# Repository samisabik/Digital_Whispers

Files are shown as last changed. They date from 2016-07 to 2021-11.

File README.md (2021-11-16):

## Digital Whispers

In a world populated by an increasing abundance of Artificial Intelligences (AI), it has become more and more important for us to understand the behaviours of our smarter machines. AI promises perfect systems designed to master their functions. As humans, we have imbued these artificial creatures with senses. We have given them the ability to communicate to an ever nearer degree of naturalness; speech and hearing being the most developed. With these efforts, we expect these systems to be as perfect as we have designed them; but what about errors? Beautiful mispronunciation? Hearing loss? Faded meaning? What about the little misunderstandings that makes us human? Can a machine suffer from them and experience them also?

Digital Whispers is an installation that sets seven computers and one human in to a game of Chinese Whispers. The visitor inputs the seed sentence into the “ear” of the first computer and the dialog of ethereal whispers continues in a chain until every machine has had its say. Each computer can hear and talk. It whispers to its neighbour the sentence as it comes into its “ears”. Errors evolves involuntary (or not), creating word chimeras, often resulting in absurd sentences only a robot could have created. The final phrase spoken back to the visitor, most often with surreal overtones, leaves to question the machine as a reflection of humanity.

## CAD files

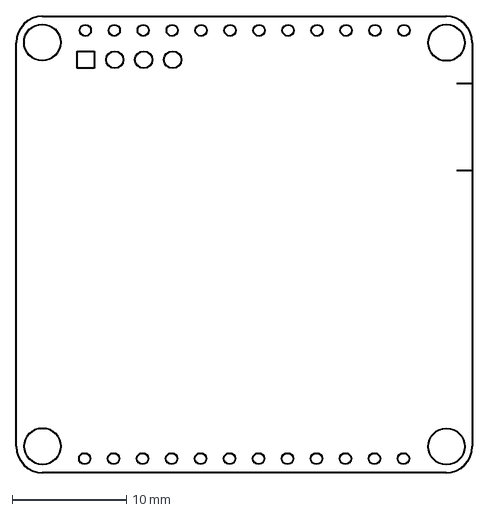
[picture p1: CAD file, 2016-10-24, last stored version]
physical/drawings/NanoPi-NEO-Air-1608.dxf
40.0 x 40.0 mm

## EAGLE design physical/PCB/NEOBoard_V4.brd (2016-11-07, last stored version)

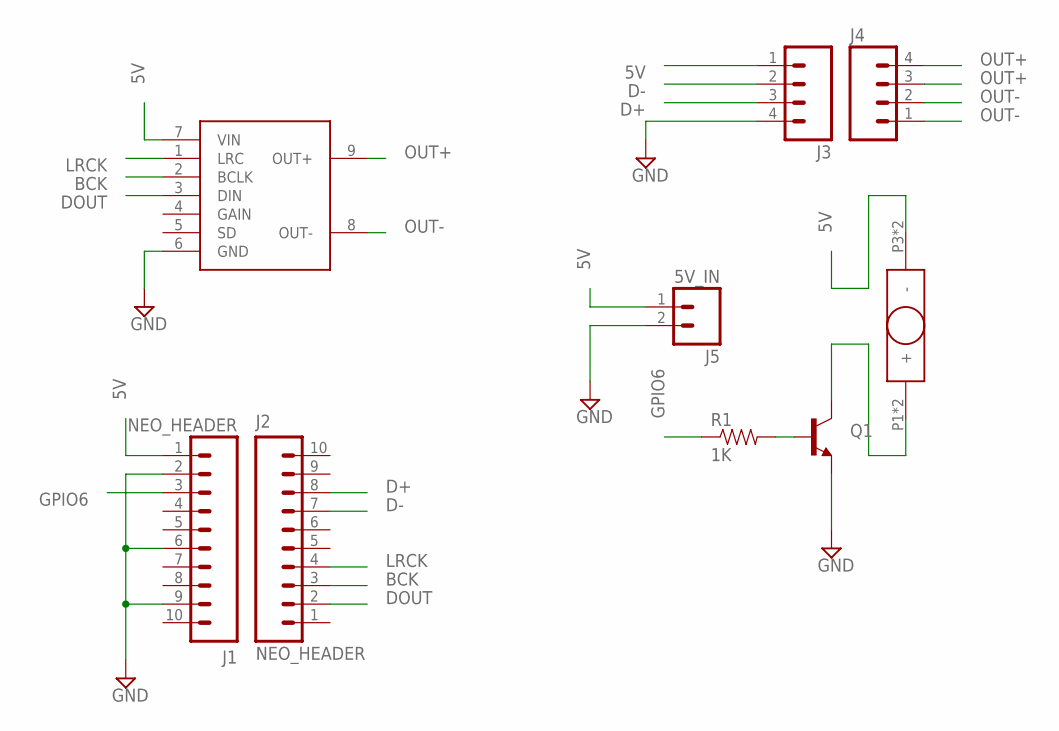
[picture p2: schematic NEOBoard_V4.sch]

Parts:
J1, J2: NEO_HEADER; 1X10_NO_SILK
J3, J4: M04NO_SILK_ALL_ROUND; 1X04_NO_SILK_ALL_ROUND
J5: 5V_IN; 1X02_NO_SILK
Q1: TRANSISTOR_NPNTO92; TO-92
R1: 1K; AXIAL-0.3
U$1: I2S_BREAKOUT
U$2: FUSER; FUSE

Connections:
5V: J1.1, J3.1, J5.1, U$1.7 (VIN), U$2.P3 (-), U$2.P4 (-)
BCK: J2.3, U$1.2 (BCLK)
D+: J2.8, J3.3
D-: J2.7, J3.2
DOUT: J2.2, U$1.3 (DIN)
GND: J1.2, J1.6, J1.9, J3.4, J5.2, Q1.1 (E), U$1.6 (GND)
GPIO6: J1.3, R1.P$1 (1)
LRCK: J2.4, U$1.1 (LRC)
unnamed: Q1.2 (B), R1.P$2 (2)
unnamed: Q1.3 (C), U$2.P1 (+), U$2.P2 (+)
OUT+: J4.3, J4.4, U$1.9 (OUT+)
OUT-: J4.1, J4.2, U$1.8 (OUT-)

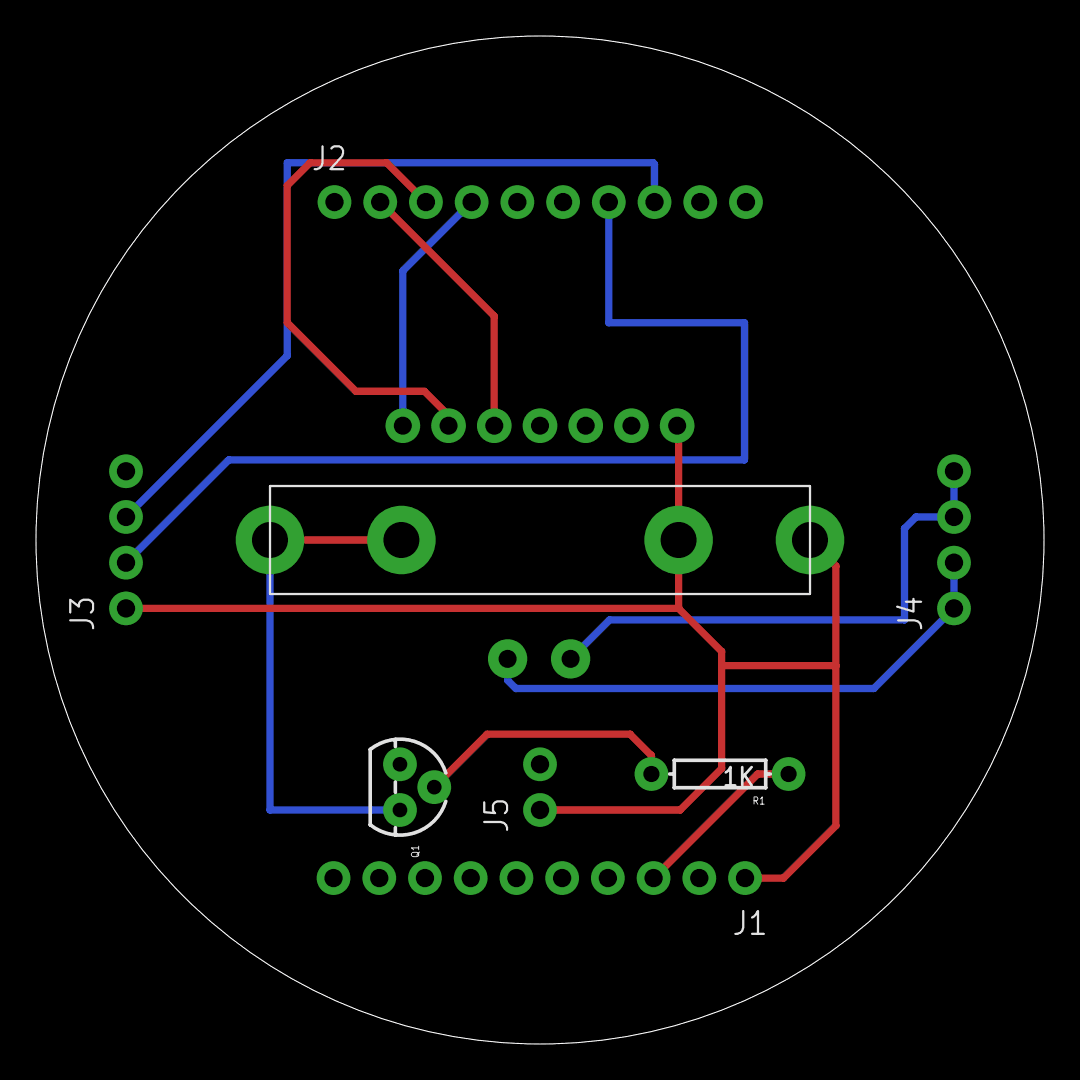
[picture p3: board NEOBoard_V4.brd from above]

Board: 2 copper layers, 56.0 x 56.0 mm, 9 parts (1 on the bottom side), 12 nets.

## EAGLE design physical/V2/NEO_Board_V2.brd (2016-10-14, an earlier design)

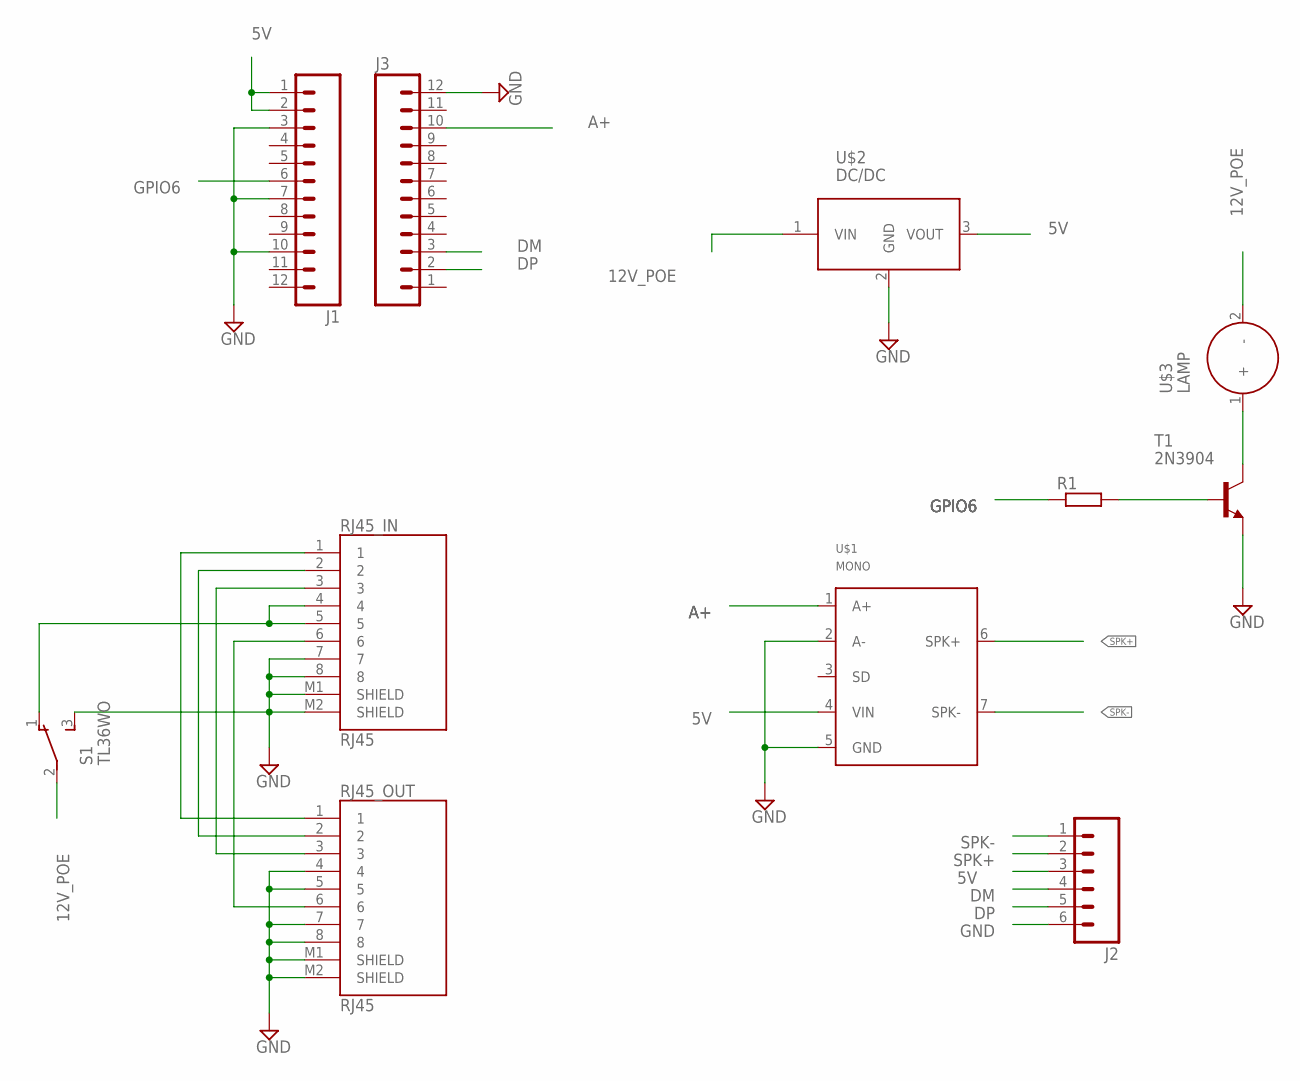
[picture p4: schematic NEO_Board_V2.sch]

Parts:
J1, J3: M12PTH; 1X12
J2: M06NO_SILK_FEMALE_PTH; 1X06_NO_SILK
R1: R-EU_0207/10; 0207/10
RJ45_IN, RJ45_OUT: RJ45
S1: TL36WO; TL3XWO
T1: 2N3904; TO92
U$1: MONO; MONO_AMP
U$2: DC/DC
U$3: LAMP

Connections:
5: RJ45_IN.4, RJ45_IN.5, S1.1 (O)
5V: J1.1, J1.2, J2.3, U$1.4 (VIN), U$2.3 (VOUT)
12V_POE: S1.2, U$2.1 (VIN), U$3.2 (-)
A+: J3.10, U$1.1 (A+)
DM: J2.4, J3.3
DP: J2.5, J3.2
GND: J1.3, J1.7, J1.10, J2.6, J3.12, RJ45_IN.7, RJ45_IN.8, RJ45_IN.M1 (SHIELD), RJ45_IN.M2 (SHIELD), RJ45_OUT.4, RJ45_OUT.5, RJ45_OUT.7, RJ45_OUT.8, RJ45_OUT.M1 (SHIELD), RJ45_OUT.M2 (SHIELD), S1.3 (S), T1.3 (E), U$1.2 (A-), U$1.5 (GND), U$2.2 (GND)
GPIO6: J1.6, R1.1
unnamed: R1.2, T1.2 (B)
unnamed: RJ45_IN.6, RJ45_OUT.6
unnamed: T1.1 (C), U$3.1 (+)
unnamed: RJ45_IN.3, RJ45_OUT.3
unnamed: RJ45_IN.2, RJ45_OUT.2
unnamed: RJ45_IN.1, RJ45_OUT.1
SPK+: J2.2, U$1.6 (SPK+)
SPK-: J2.1, U$1.7 (SPK-)

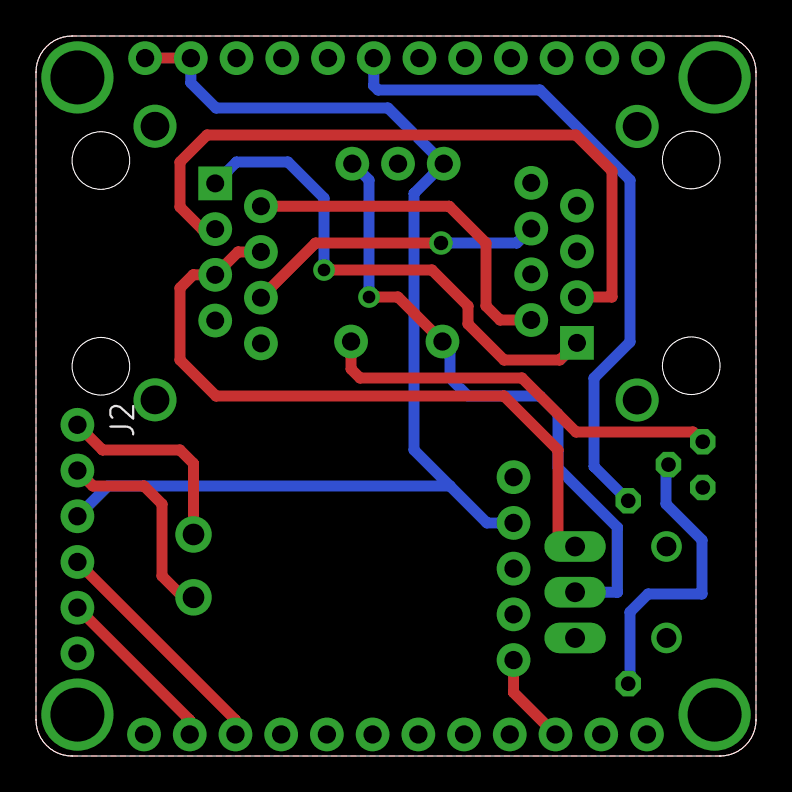
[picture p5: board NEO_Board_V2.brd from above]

Board: 2 copper layers, 40.0 x 40.0 mm, 11 parts (0 on the bottom side), 16 nets.

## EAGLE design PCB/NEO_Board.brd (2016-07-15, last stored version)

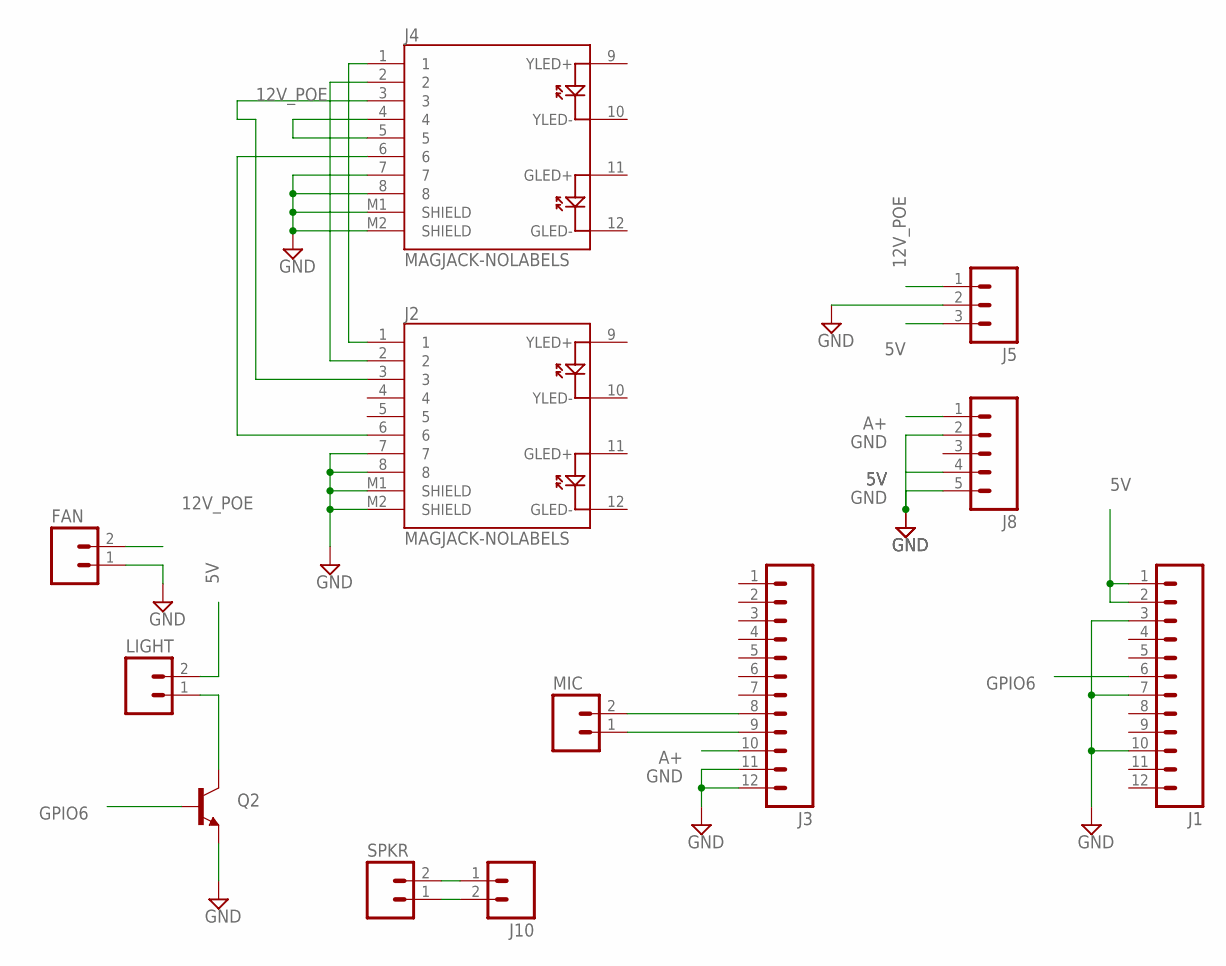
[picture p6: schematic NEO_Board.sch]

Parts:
FAN: M02PTH; 1X02
J1, J3: M12PTH; 1X12
J2, J4: MAGJACK-NOLABELS; MAGJACK
J5: M03PTH; 1X03
J8: M05PTH; 1X05
J10: M023.5MM; SCREWTERMINAL-3.5MM-2
LIGHT: M02PTH; 1X02
MIC: M02PTH; 1X02
Q2: TRANSISTOR_NPNP2N2222A; TO-92
SPKR: M02PTH; 1X02

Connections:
5V: J1.1, J1.2, J5.3, J8.4, LIGHT.2
12V_POE: FAN.2, J4.4, J4.5, J5.1
A+: J3.10, J8.1
GND: FAN.1, J1.3, J1.7, J1.10, J2.7, J2.8, J2.M1 (SHIELD), J2.M2 (SHIELD), J3.11, J3.12, J4.7, J4.8, J4.M1 (SHIELD), J4.M2 (SHIELD), J5.2, J8.2, J8.5, Q2.3 (E)
GPIO6: J1.6, Q2.2 (B)
MICN: J3.9, MIC.1
MICP: J3.8, MIC.2
unnamed: J2.1, J4.1
unnamed: J2.2, J4.2
unnamed: J2.3, J4.3
unnamed: J2.6, J4.6
unnamed: LIGHT.1, Q2.1 (C)
unnamed: J10.1, SPKR.2
unnamed: J10.2, SPKR.1

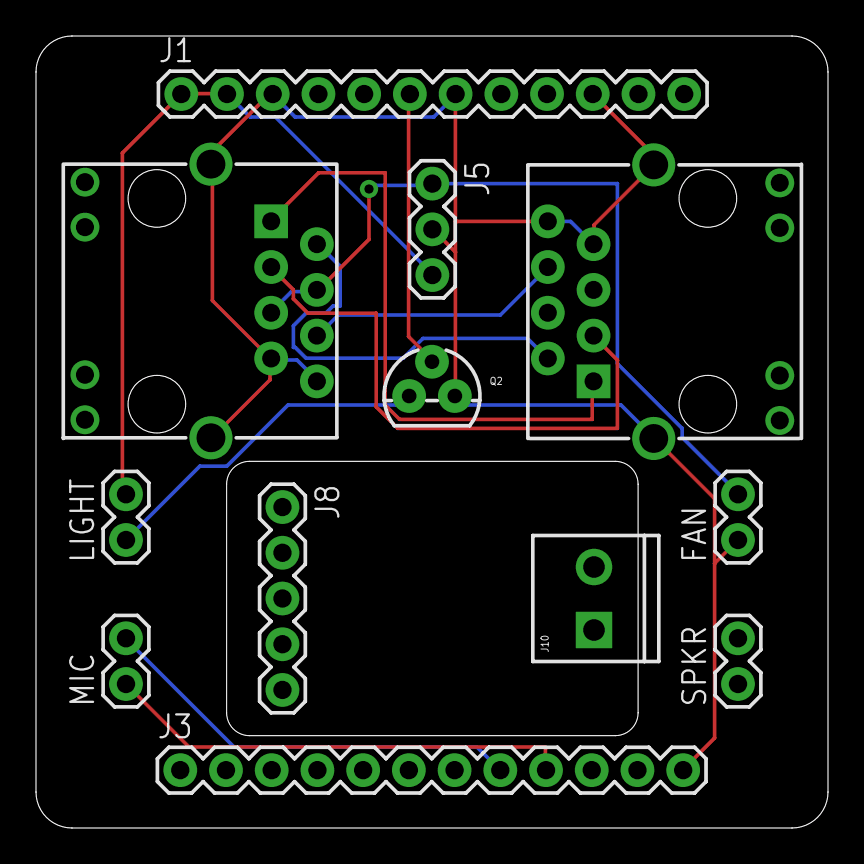
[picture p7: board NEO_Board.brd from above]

Board: 2 copper layers, 44.0 x 44.0 mm, 12 parts (0 on the bottom side), 14 nets.

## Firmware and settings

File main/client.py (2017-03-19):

#!/usr/bin/env python
import os,sys,random,json,zmq,utils
from utils import *
from os.path import join, dirname
from sys import exit
from time import sleep
from watson_developer_cloud import TextToSpeechV1,SpeechToTextV1

## IBM Watson API (Germany LOC)
text_to_speech = TextToSpeechV1(
	username='b2cb07cb-14f8-4262-9a57-331747a50639',
	password='xKy1K6fSOvU0')
speech_to_text = SpeechToTextV1(
	username='4ad77d91-b0ab-4a70-bf37-6af867f83599',
	password='s32ny3e1eOTW')

TTSvoices = ["en-US_AllisonVoice","en-US_LisaVoice","en-GB_KateVoice","en-US_MichaelVoice"]
voice = TTSvoices[random.randrange(0, 4)]

context = zmq.Context()
statesock = context.socket(zmq.PUB)
statesock.setsockopt(zmq.LINGER, 0)
statesock.bind("tcp://*:5560")

cmdsock = context.socket(zmq.REP)
cmdsock.setsockopt(zmq.LINGER, 0)
cmdsock.bind("tcp://*:5561")

state = "waiting"

def changestate(newstate, data=""):
	global state
	state = newstate
	statesock.send_string(state + ":" + data)
	print "state", state

def ok():
	cmdsock.send_string("OK")

def error():
	cmdsock.send_string("ERROR")
	exit()

def expect(expectedstate):
	if (state == expectedstate):
		ok()
		sleep(0.1)
	else:
		print("Expected state", expectedstate, "not", state)
		error()

rec = utils.Recorder(channels=1)

changestate("waiting")

recfile = None
while True:
	[cmd, data] = cmdsock.recv().split(':')
	print "received", cmd, data

	if cmd == "LISTEN":
		expect("waiting")

		recfile2 = rec.open('output/record.wav', 'wb')
		recfile2.start_recording()
		changestate("listening")

	elif cmd == "STOP_LISTEN":
		expect("listening")

		recfile2.stop_recording()
		recfile2.close()
		with open('output/record.wav', 'rb') as audio_file:
			result = json.dumps(speech_to_text.recognize(audio_file, content_type='audio/wav'))
			parsed_json = json.loads(result)
		try:
			text = parsed_json['results'][0]['alternatives'][0]['transcript']
		except:
			print "STT failed !"
			text = ""
		changestate("waiting", text)

	elif cmd == "TALK":
		expect("waiting")

		changestate("talking")
		with open('output/synthesize.wav', 'wb') as audio_file:
			audio_file.write(text_to_speech.synthesize(data,voice,"audio/wav"))
		os.system('play -q --ignore-length output/synthesize.wav')
		changestate("waiting")

	elif cmd == "DIE":
		ok()
		exit()

	else:
		error()
		exit()

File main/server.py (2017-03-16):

#!/usr/bin/env python
import datetime, time, os, json, zmq
from utils import *
from os.path import join, dirname
from watson_developer_cloud import TextToSpeechV1,SpeechToTextV1
import RPi.GPIO as GPIO

## Input / Output log file
ts = time.time()
filename = datetime.datetime.fromtimestamp(ts).strftime('%Y%m%d_%H%M')

## Setup GPIOs
GPIO.setmode(GPIO.BCM) 
GPIO.setwarnings(False)
for x in range(2, 9):
	GPIO.setup(x, GPIO.OUT)

## MAKE A FOR LOOP !

## IBM Watson API Call
text_to_speech = TextToSpeechV1(
	username='c62c972e-727b-4ee3-9436-b808cbbca69a',
	password='BkSjWMgbDopX')
speech_to_text = SpeechToTextV1(
	username='22d00128-ea8c-4d10-a0e8-7059450c7de7',
	password='x8OOTkHv0vXz')

LEVEL = 200
NUM_CLIENTS = 7
clients = [Client('whisper_'+str(x)) for x in range(0,NUM_CLIENTS)]

os.system('clear')
print "# starting whisper_master"

THRESHOLD = audio_int(50) + LEVEL

while True:
	listen_for_speech(THRESHOLD,1)
	with open('output/record.wav', 'rb') as audio_file:
		result = json.dumps(speech_to_text.recognize(audio_file, content_type='audio/wav'))
		parsed_json = json.loads(result)
	try:
		text = parsed_json['results'][0]['alternatives'][0]['transcript']
		print "# starting with phrase : " + text
	except:
		print "# STT failed!"
		continue
	with open('output/'+filename+'.txt', 'a') as text_file:
		text_file.write(text + '\n')
	for i, client in enumerate(clients):
		print "\n"
		if i+1 < len(clients):
			nextclient = clients[i+1]
		else:
			nextclient = None
		try:
			if nextclient:
				nextclient.send("LISTEN")
				nextclient.expect("listening")
		except (zmq.ZMQError, UnexpectedStateError, FailedRequestError) as e:
			print nextclient.addr, "failed:", e
			nextclient.reset()
			nextclient = None
		GPIO.output(i+2, 1)
		time.sleep(1)
		try:
			client.send("TALK", text)
			client.expect("talking")
			client.expect("waiting", 20*1000)
		except (zmq.ZMQError, UnexpectedStateError, FailedRequestError) as e:
			print client.addr, "failed:", e
			client.reset()
			GPIO.output(i+2, 0)
		time.sleep(1) ## addin extra time to add some fucking up
		GPIO.output(i+2, 0)
		try:
			if nextclient:
				nextclient.send("STOP_LISTEN")

				clienttext = nextclient.expect("waiting", 20*1000)
				if clienttext:
					print "TTS result:", '"' + clienttext + '"'
					text = clienttext
				else:
					print "TTS result: (no text)"
		except (zmq.ZMQError, UnexpectedStateError, FailedRequestError) as e:
			print nextclient.addr, "failed:", e
			nextclient.reset()
	with open('output/'+filename+'.txt', 'a') as text_file:
		text_file.write(text + '\n\n')

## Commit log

2016-07-15 clean up + PCB
    [NEO_Board.brd, NEO_Board.sch]
2016-10-14 big update // clean up
    [NEO_Board.brd, NEO_Board.sch, NEO_Board_V2.brd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]
2016-10-17 added debug TTS
    [NEO_Board_V2.brd, NEO_Board_V2.sch, NanoPi-NEO-Air-1608.dxf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]
2016-10-18 modif setup.sh
    [NanoPi-NEO-Air-1608.dxf]
2016-11-07 clean up + gitignore /tools
    [NEOBoard_V3.brd, NEOBoard_V3.sch, NEOBoard_V4.brd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]
2017-01-25 spring cleaning
    [NEOBoard_V3.brd, NEOBoard_V3.sch, NEOBoard_V4.brd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]
2017-03-07 make audio paths relative to current dir
2017-03-07 server logging improvements + client linger fix
    [client.py, server.py]
2017-03-07 messing around with timeout values and socket options
2017-03-15 fixed bug on client.py
    [client.py]

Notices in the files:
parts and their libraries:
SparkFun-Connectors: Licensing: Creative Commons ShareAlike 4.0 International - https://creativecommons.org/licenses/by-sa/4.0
